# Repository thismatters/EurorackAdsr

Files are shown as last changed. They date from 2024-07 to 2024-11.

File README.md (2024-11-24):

# ADSR

```
   /\D
 A/  \_____
 /      S  \R
/           \
```

An envelope generator with classic ADSR profile centered around the 555 timer, responsive to a gate input. Adjustable durations for attack, duration, and release; and adjustable voltage for the sustain portion.

The circuit here is based on the [Yusynth ADSR (newer version)](https://yusynth.net/Modular/EN/ADSR/index_latest.html) with minor tweaks to make it more Eurorack friendly. The changes I've made are thus:
* Selected resistors appropriate for +/-12V rails,
* Added polarity protection so that a backward power header doesn't fry anything (twin series schotty diodes: BAT54SL),
* Full surface mount design.

The Yusynth page is a treasure trove of information about this circuit that I am too amateur to claim as my own; please read that outstanding page before using this circuit. The page provides many details and other implementations of this circuit that you may find suitable.

The KiCAD project here uses the library/footprints [found in my companion repo](https://github.com/thismatters/EurorackKiCAD).

## Width

6hp on a standard 3U rack.

## Inputs

Accepts gate input via patch cable, has pushbutton for manual gating.
Four knobs set the shape of the envelope. A toggle switch sets the response of the envelope generator between fast and slow.

## Outputs

Envelope and inverted envelope outputs. LED visualizes the output signal.

## Vendors

There are part numbers in the [BOM](adsr.csv) for many of the parts (not for basic passives though) at the following vendors:

* [Mouser](https://www.mouser.com): Needs no introduction. Get your ICs from here (or [digikey](https://www.digikey.com)).
* [Tayda Electronics](https://www.taydaelectronics.com/): Good supplier for passive components; audio jacks, and potentiometers. Their audio jacks are slightly smaller than the thonkiconn from thonk.
* [Love My Switches](https://lovemyswitches.com/): Has [really good knobs](https://lovemyswitches.com/anodized-aluminum-knob-the-lo-fi-1-4-smooth-shaft-12-5mm-od/) to go on those potentiometers!
* [OSHPark](https://oshpark.com/): Fast and (relatively) cheap PCB manufacturer. [V2 board](https://oshpark.com/shared_projects/UEztaF3P) works great!

## Changelog

### V2

* Fixed decay/sustain relation (swapped terminals of op amp U2(C))
* Fixed direction of decay potentiometer (swapped pins 1 and 3 of RV3)
* Fixed polarity of tantalum capacitors
* Bigger hole for LED bezel
* Fixed part number for NPN transistors

### V3 (unreleased)

* new design language

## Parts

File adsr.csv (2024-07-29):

# | Reference | Qty | Value | Footprint | DNP | Vendor | PartNum
1 | C1, C2 | 2 | 22u 50V | Capacitor_THT:CP_Radial_D5.0mm_P2.50mm
2 | C3, C5 | 2 | 10n | Capacitor_SMD:C_0805_2012Metric
3 | C4 | 1 | 10u 35V Tant | Capacitor_THT:CP_Radial_D5.0mm_P2.50mm
4 | C6, C7 | 2 | 100n | Capacitor_SMD:C_0805_2012Metric
5 | C8 | 1 | 1u 50V Tant | Capacitor_THT:CP_Radial_D5.0mm_P2.50mm
6 | D1, D2, D3, D4, D5 | 5 | 1N4148 | Diode_SMD:D_SOD-323_HandSoldering
7 | D6 | 1 | LED | LED_THT:LED_D3.0mm
8 | D7, D8 | 2 | BAT54S | Package_TO_SOT_SMD:SOT-23 |  | Mouser | 863-BAT54SLT1G
9 | J1, J2, J3 | 3 | AudioJack2_SwitchT | Eurorack:AudioJack2_Tayda_A-2566 |  | Tayda | A-2566
10 | J4 | 1 | Conn_02x05_Odd_Even | Eurorack:PinHeader_2x05_P2.54mm_Vertical |  | Tayda | A-2939
11 | JP1 | 1 | Jumper_2_Bridged | Connector_PinHeader_2.54mm:PinHeader_1x02_P2.54mm_Vertical
12 | Q1, Q2, Q3 | 3 | BC547 | Package_TO_SOT_THT:TO-92L_Inline_Wide |  | Mouser | 637-BC547C
13 | Q4 | 1 | BS170 | Package_TO_SOT_THT:TO-92_Inline |  | Mouser | 512-BS170
14 | R1, R2, R9 | 3 | 10 | Resistor_SMD:R_0805_2012Metric
15 | R3 | 1 | 10K | Resistor_SMD:R_0805_2012Metric
16 | R4 | 1 | 47K | Resistor_SMD:R_0805_2012Metric
17 | R5 | 1 | 1.2M | Resistor_SMD:R_0805_2012Metric
18 | R6, R12 | 2 | 1M | Resistor_SMD:R_0805_2012Metric
19 | R7, R8, R10, R11 | 4 | 22K | Resistor_SMD:R_0805_2012Metric
20 | R13, R16 | 2 | 100 | Resistor_SMD:R_0805_2012Metric
21 | R14 | 1 | 120 | Resistor_SMD:R_0805_2012Metric
22 | R15 | 1 | 680 | Resistor_SMD:R_0805_2012Metric
23 | R17 | 1 | 4.7K | Resistor_SMD:R_0805_2012Metric
24 | R18, R22, R23 | 3 | 1K | Resistor_SMD:R_0805_2012Metric
25 | R19, R21 | 2 | 100K | Resistor_SMD:R_0805_2012Metric
26 | R20 | 1 | 150K | Resistor_SMD:R_0805_2012Metric
27 | RV1, RV2, RV3 | 3 | A1M | Eurorack:Potentiometer_RV16AF-41-15R1 |  | Tayda | A-2425
28 | RV4 | 1 | B10K | Eurorack:Potentiometer_RV16AF-41-15R1 |  | Tayda | A-2969
29 | SW1 | 1 | SW_Push | Eurorack:PushButton_Tayda_A-5051 |  | Tayda | A-5051
30 | SW2 | 1 | SW_DPDT_x2 | Eurorack:Switch_DPDT_Tayda_A-5752 |  | Tayda | A-6809
31 | U1 | 1 | ICM7555xB | Package_SO:SOIC-8_3.9x4.9mm_P1.27mm |  | Mouser | 968-ICM7555CBAZ-T
32 | U2 | 1 | TL074 | Package_SO:SOIC-14_3.9x8.7mm_P1.27mm |  | Mouser | 595-TL074CN

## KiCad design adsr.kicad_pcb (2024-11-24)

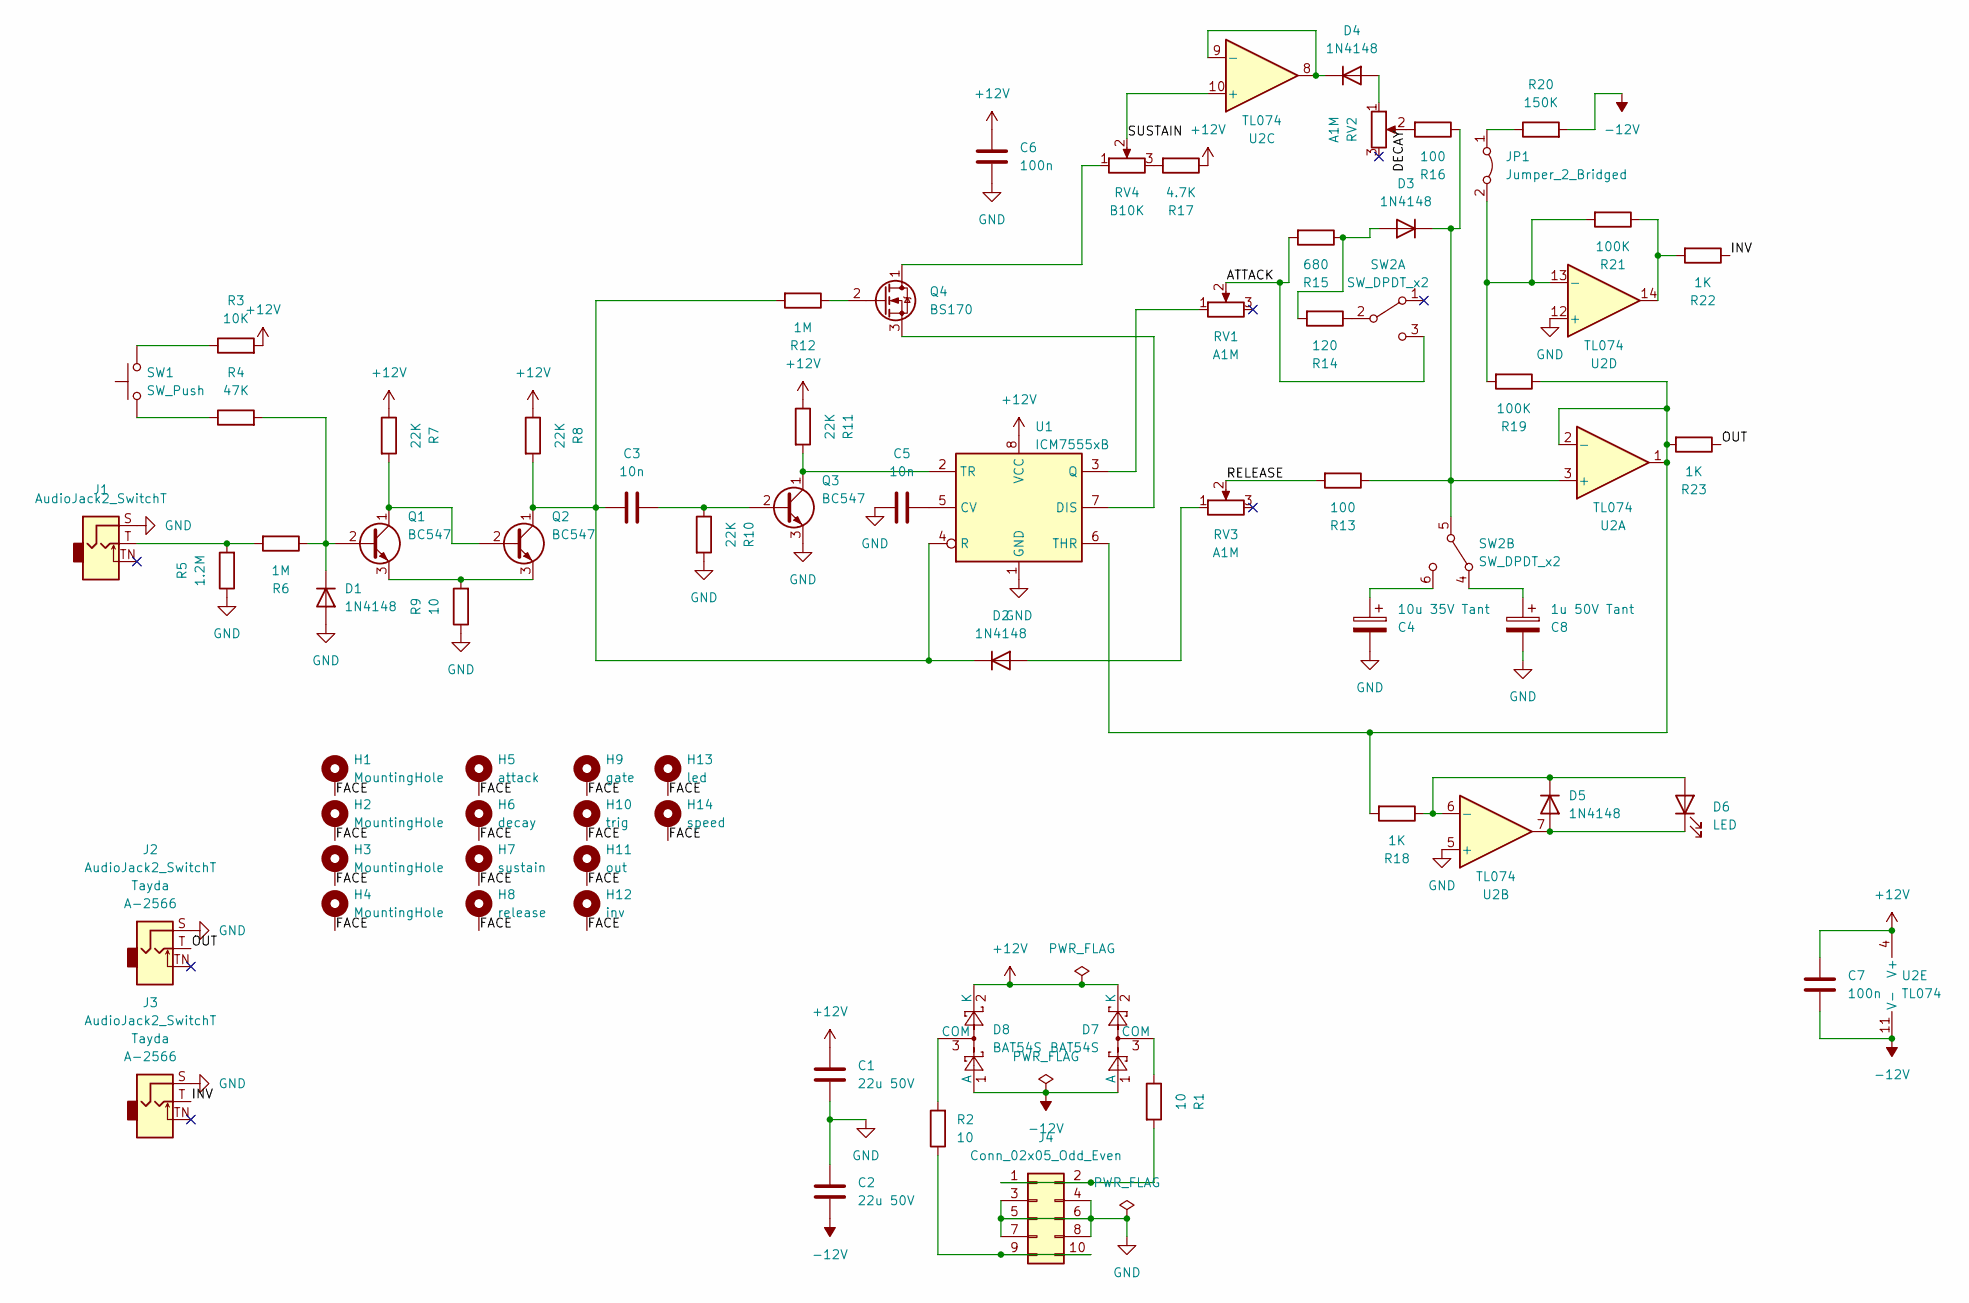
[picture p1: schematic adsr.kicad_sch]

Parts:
C1, C2: 22u 50V; CP_Radial_D5.0mm_P2.50mm
C3, C5: 10n; C_0805_2012Metric
C4: 10u 35V Tant; CP_Radial_D5.0mm_P2.50mm
C6, C7: 100n; C_0805_2012Metric
C8: 1u 50V Tant; CP_Radial_D5.0mm_P2.50mm
D1, D2, D3, D4, D5: 1N4148; D_SOD-323_HandSoldering
D6: LED; LED_D3.0mm
D7, D8: BAT54S; SOT-23; PartNum 863-BAT54SLT1G
H1, H2, H3, H4: MountingHole; Mech-MountingHole
H5: attack; Mech-Potentiometer-Hole_level
H6: decay; Mech-Potentiometer-Hole_level
H7: sustain; Mech-Potentiometer-Hole_level
H8: release; Mech-Potentiometer-Hole_level
H9: gate; Mech-AudioJack-Hole-Input-Gate
H10: trig; Mech-PushButton-Hole_Tayda_A-5051
H11: out; Mech-AudioJack-Hole-Output-CV
H12: inv; Mech-AudioJack-Hole-Output-CV
H13: led; Mech-LED-Hole-3mm-Bezel
H14: speed; Mech-2M_Switch-Hole
J1, J2, J3: AudioJack2_SwitchT; AudioJack2_Tayda_A-2566; PartNum A-2566
J4: Conn_02x05_Odd_Even; PinHeader_2x05_P2.54mm_Vertical; PartNum A-2939
JP1: Jumper_2_Bridged; PinHeader_1x02_P2.54mm_Vertical
Q1, Q2, Q3: BC547; TO-92L_Inline_Wide; PartNum 637-BC547C
Q4: BS170; TO-92_Inline; PartNum 512-BS170
R1, R2, R9: 10; R_0805_2012Metric
R3: 10K; R_0805_2012Metric
R4: 47K; R_0805_2012Metric
R5: 1.2M; R_0805_2012Metric
R6, R12: 1M; R_0805_2012Metric
R7, R8, R10, R11: 22K; R_0805_2012Metric
R13, R16: 100; R_0805_2012Metric
R14: 120; R_0805_2012Metric
R15: 680; R_0805_2012Metric
R17: 4.7K; R_0805_2012Metric
R18, R22, R23: 1K; R_0805_2012Metric
R19, R21: 100K; R_0805_2012Metric
R20: 150K; R_0805_2012Metric
RV1, RV2, RV3: A1M; Potentiometer_RV16AF-41-15R1; PartNum A-2425
RV4: B10K; Potentiometer_RV16AF-41-15R1; PartNum A-2969
SW1: SW_Push; PushButton_Tayda_A-5051; PartNum A-5051
SW2: SW_DPDT_x2; Switch_DPDT_Tayda_A-5752; PartNum A-6809
U1: ICM7555xB; SOIC-8_3.9x4.9mm_P1.27mm; PartNum 968-ICM7555CBAZ-T
U2: TL074; SOIC-14_3.9x8.7mm_P1.27mm; PartNum 595-TL074CN

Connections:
+12V: C1.1, C6.1, C7.1, D7.2 (K), D8.2 (K), R3.2, R7.1, R8.1, R11.1, R17.1, U1.8 (VCC), U2.4 (V+)
-12V: C2.2, C7.2, D7.1 (A), D8.1 (A), R20.2, U2.11 (V-)
/ATTACK: R15.2, RV1.2, SW2.3 (C)
/DECAY: R16.2, RV2.2
/FACE: H1.1, H2.1, H3.1, H4.1, H5.1, H6.1, H7.1, H8.1, H9.1, H10.1, H11.1, H12.1, H13.1, H14.1
/INV: J3.T, R22.1
/OUT: J2.T, R23.1
/RELEASE: R13.2, RV3.2
/SUSTAIN: RV4.2, U2.10 (+)
GND: C1.2, C2.1, C4.2, C5.1, C6.2, C8.2, D1.2 (A), J1.S, J2.S, J3.S, J4.3, J4.4, J4.5, J4.6, J4.7, J4.8, Q3.3 (E), R5.1, R9.1, R10.2, U1.1 (GND), U2.5 (+), U2.12 (+)
unnamed: D1.1 (K), Q1.2 (B), R4.2, R6.1
unnamed: D2.2 (A), RV3.1
unnamed: C3.1, D2.1 (K), Q2.1 (C), R8.2, R12.2, U1.4 (R)
unnamed: D3.2 (A), R14.2, R15.1
unnamed: D3.1 (K), R13.1, R16.1, SW2.5 (B), U2.3 (+)
unnamed: D4.2 (A), RV2.1
unnamed: D4.1 (K), U2.8, U2.9 (-)
unnamed: D5.2 (A), D6.1 (K), U2.7
unnamed: D5.1 (K), D6.2 (A), R18.1, U2.6 (-)
unnamed: D7.3 (COM), R1.1
unnamed: D8.3 (COM), R2.2
unnamed: J1.T, R5.2, R6.2
unnamed: J4.1, J4.2, R1.2
unnamed: J4.9, J4.10, R2.1
unnamed: JP1.1 (A), R20.1
unnamed: JP1.2 (B), R19.2, R21.2, U2.13 (-)
unnamed: Q1.1 (C), Q2.2 (B), R7.2
unnamed: Q1.3 (E), Q2.3 (E), R9.2
unnamed: C3.2, Q3.2 (B), R10.1
unnamed: Q3.1 (C), R11.2, U1.2 (TR)
unnamed: Q4.1 (D), RV4.1
unnamed: Q4.2 (G), R12.1
unnamed: Q4.3 (S), U1.7 (DIS)
unnamed: R3.1, SW1.2
unnamed: R4.1, SW1.1
unnamed: R17.2, RV4.3
unnamed: R21.1, R22.2, U2.14
unnamed: R14.1, SW2.2 (B)
unnamed: C8.1, SW2.4 (A)
unnamed: C4.1, SW2.6 (C)
unnamed: C5.2, U1.5 (CV)
unnamed: RV1.1, U1.3 (Q)
unnamed: R18.2, R19.1, R23.2, U1.6 (THR), U2.1, U2.2 (-)

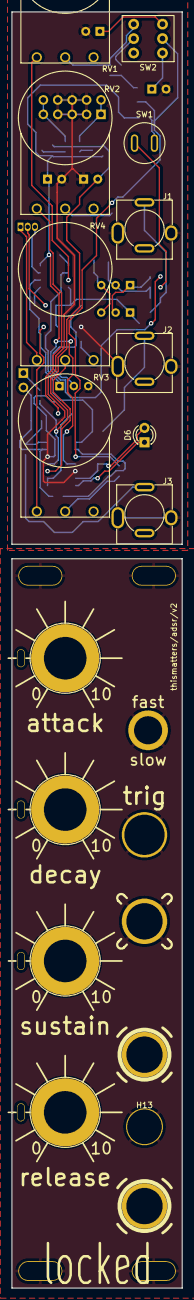
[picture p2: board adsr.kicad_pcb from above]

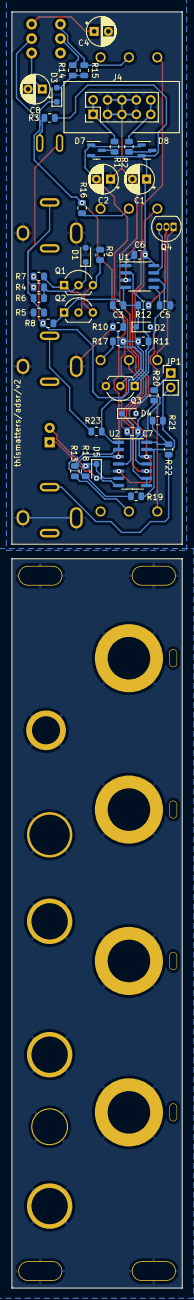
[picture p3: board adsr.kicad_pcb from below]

Board: 2 copper layers, 30.0 x 224.8 mm, 70 parts (46 on the bottom side), 43 nets.

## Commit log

2024-01-03 getting started
    [adsr.csv, adsr.kicad_pcb, adsr.kicad_sch]
2024-01-03 first draft pcb
    [adsr.kicad_pcb, adsr.kicad_sch]
2024-01-04 slightly more compact pcb
    [adsr.kicad_pcb, adsr.kicad_sch]
2024-01-15 prepped for manu
    [adsr.kicad_pcb]
2024-01-15 better bom
    [adsr.csv]
2024-01-15 removing non-parts from BOM
    [adsr.csv, adsr.kicad_sch]
2024-03-03 v2 fixes
    [adsr.csv, adsr.kicad_pcb, adsr.kicad_sch]
2024-07-29 updating BOM for v2
    [adsr.csv, adsr.kicad_sch]
2024-11-24 new design language, adding pcb to readme
    [adsr.kicad_pcb, adsr.kicad_sch]
